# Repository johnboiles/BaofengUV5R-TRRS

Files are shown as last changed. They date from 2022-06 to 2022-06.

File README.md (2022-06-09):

Baofeng UV5R TRRS Adapter
=========================
http://github.com/johnboiles/BaofengUV5R-TRRS

A tiny board, which allows a smartphone or similiar device to connect to the Baofeng UV5R radio via a [TRRS audio connector](https://en.wikipedia.org/wiki/Phone_connector_%28audio%29#TRRS_standards). It allows for connecting the radio to a software [TNC](https://en.wikipedia.org/wiki/Terminal_node_controller) app such as [APRSDroid](http://aprsdroid.org/) or [PocketPacket](https://itunes.apple.com/us/app/pocketpacket/id336500866?mt=8). Solder on the components, solder on the cables, then provide some stress relief, (I use solid-core wire and heat shrink tubing), and you can use your UV5R with your smartphone for APRS on the cheap.

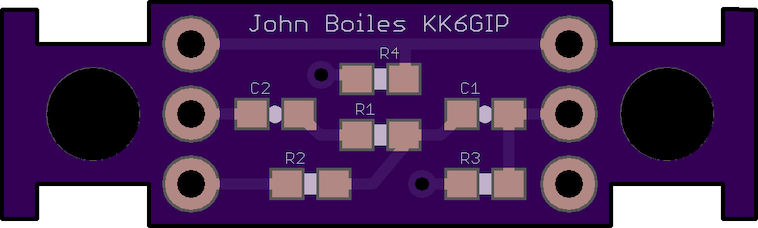
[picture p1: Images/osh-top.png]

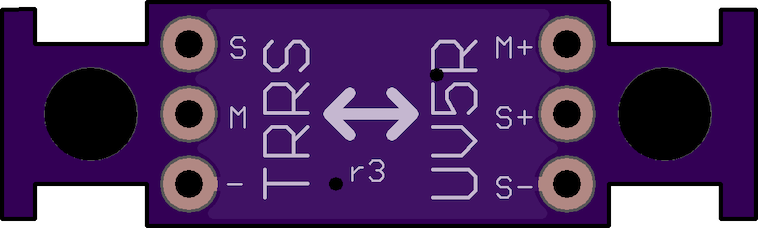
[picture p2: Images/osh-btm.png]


Pictures
--------

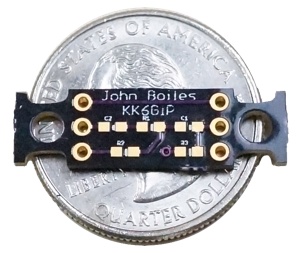
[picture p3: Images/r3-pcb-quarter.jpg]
The PCB and a US quarter

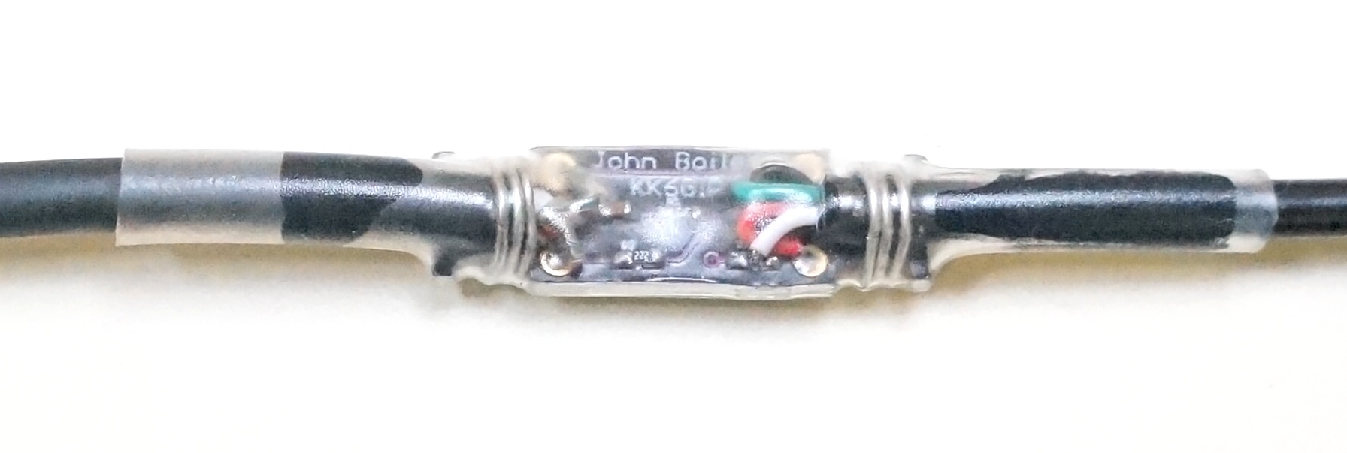
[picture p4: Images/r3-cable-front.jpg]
The front of an assembled cable

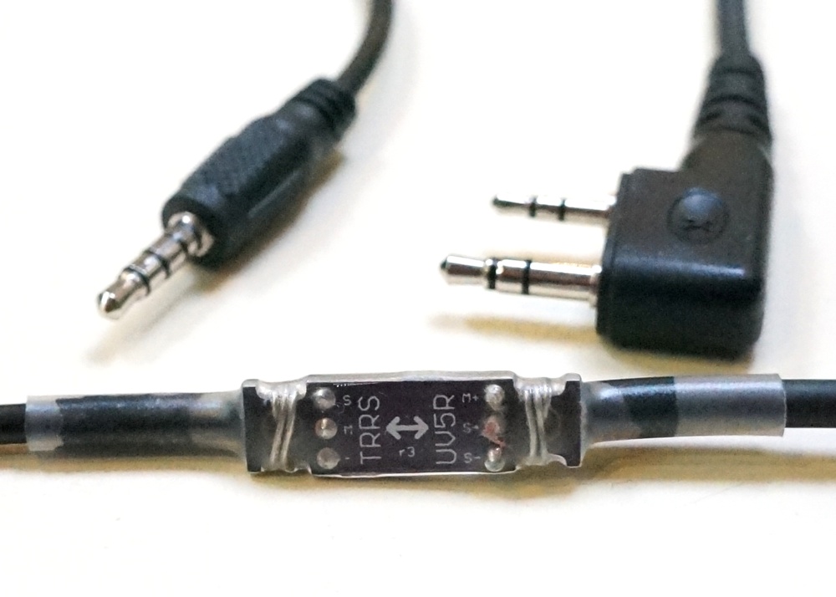
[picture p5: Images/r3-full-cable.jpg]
The back of the PCB with the cable ends


Notes
-----
A small capacitor and 3 resistors to trick the iPhone into thinking a microphone was connected. This part of the schematic was inspired by [this article](http://www.creativedistraction.com/demos/sensor-data-to-iphone-through-the-headphone-jack-using-arduino/) on connecting Arduino to an iPhone.

A small capacitor on the speaker out of the radio removes any DC bias. (I'm not sure why this was necessary, but in my testing it made receipt of packets much more reliable.)

A 100Ω resistor is employed to improve detection on a variety of Android phones.

On my UV5R+, volume is maxed, vox is set to 2 and, squelch is set to 1. On my iPhone volume is also maxed.

Schematic
---------
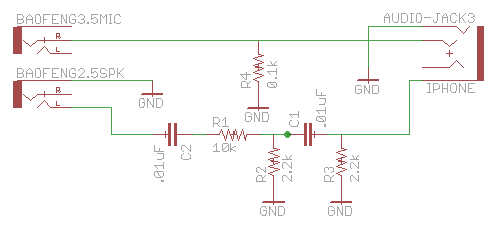
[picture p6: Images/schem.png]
Schematic


Bill of Materials
-----------------
| Qty | Part | Notes |
|-----|---|---|
| 1 | [Kenwood Type Speaker Mic Cable](https://www.argentdata.com/catalog/product_info.php?products_id=70) | You can also use 2.5mm and 3.5mm cable. |
| 1 | [3.5mm TRRS Cable](http://amzn.com/B00FJEGXLW) | |
| 1 | 10kΩ Resistor 0603 | |
| 2 | 2.2kΩ Resistor 0603 | |
| 1 | 0.1kΩ Resistor 0603 | |
| 2 | 0.01uF Capacitor 0603 | |
| 1 | 3" of 0.25" Diameter Heat Shrink Tubing | Optional |

How to Order
------------
You can order the board directly through [OSHPark](http://oshpark.com/shared_projects/qy523INb) ($1.70 for 3 boards with free shipping). Digikey or Mouser are good places to buy the resistors and capacitors.

Thanks
------

The following people have provided contributions to this design

* [kronicd VK6HAX](https://github.com/kronicd/) - optimisations to improve detection on a number of phones

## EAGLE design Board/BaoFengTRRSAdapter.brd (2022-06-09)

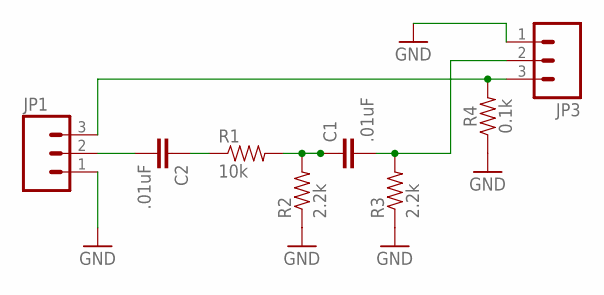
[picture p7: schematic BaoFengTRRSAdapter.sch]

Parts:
C1, C2: .01uF; 0603-CAP
JP1, JP3: M031X03_NO_SILK; 1X03_NO_SILK
R1: 10k; 0603-RES
R2, R3: 2.2k; 0603-RES
R4: 0.1k; 0603-RES

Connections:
BAOFENGMIC+: JP1.3, JP3.3, R4.2
GND: JP1.1, JP3.1, R2.1, R3.1, R4.1
unnamed: C2.2, JP1.2
unnamed: C1.1, R1.2, R2.2
unnamed: C1.2, JP3.2, R3.2
unnamed: C2.1, R1.1

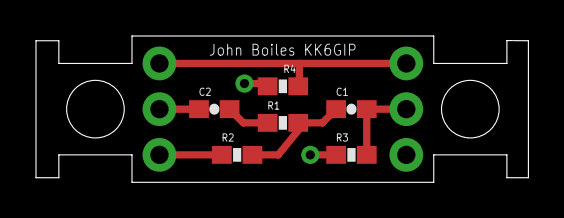
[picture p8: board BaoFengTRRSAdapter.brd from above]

Board: 2 copper layers, 27.4 x 8.1 mm, 8 parts (0 on the bottom side), 6 nets.

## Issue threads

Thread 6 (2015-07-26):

Parts List on Mouser

kd5ftn, 2015-07-26:
John, I want to say thanks for designing this little PCB and identifying the components and connectors.

I have a project where we plan to track an APRS device on a high altitude balloon, and we plan to have a number of Baofeng radios connected to Android phones running APRSDroid.

I've quickly selected the resistors & capacitors and made a Mouser project with the components. This is enough parts for 10 boards, plenty if you make any mistakes. As mentioned in other issues - this is SMD soldering and these are small 0603 parts, so be prepared for that. Personally, I will likely reflow these boards using a hot plate.

Mouser project:
http://www.mouser.com/ProjectManager/ProjectDetail.aspx?AccessID=b33edb430a

Festerstoybox, 2023-09-03:
hey, not ure if anyone still doing this little project but I just got into it. i found the list thats here has become obsolete, however you can still get the equivellent hardware so i made an updated parts list.

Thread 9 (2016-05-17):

Connecting headset and phone

fossum, 2016-05-17:
Forgive me, I'm new to this whole ham thing and I'd like to run motorcycle groups comms through the one band on the ham and arps on the other. Is this possible with a [BaoFeng UV-82HP](http://www.amazon.com/BaoFeng-UV-82HP-YELLOW-Power-Radio/dp/B015D9QYYS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) and your PCB?

Sorry for filing an issue, but I didn't see any other way...

johnboiles, 2016-05-19:
Hi @fossum. You probably can't use the same radio for both duties at the same time, but that radio should be fine for either duty.

Two things to note about this project
1) The interesting part of this project is in the RX (tricks the phone into thinking an external microphone is attached). TX can be accomplished with a simple patch cable. Some users have reported that vox gets continuously triggered with this cable when using it for TX. Personally I use standalone devices for TX (see [tinytrackuino](https://github.com/johnboiles/tinytrackuino)) and only use this cable for RX.
2) It's designed to be the cheapest way to use APRS in a pinch. Think of it like a tool you have in your toolbox for APRS, but not a bulletproof way to send and receive packets. A proper TNC might make more sense if this is something you're relying on day-to-day.

fossum, 2016-05-22:
Right, I figured you can't TX on two bands at the same time. I thought I'd just silence the APRSdroid when talking (through some custom PCB). This Trackuino seems interesting. Probably more along what I need. Thanks for the redirect.

Closed 2016-05-22.

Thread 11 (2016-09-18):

Question about Ground Connection

ref5275, 2016-09-18:
I noticed on your schematic the ground is connected to the tip on the trrs plug which is one of the audio out channels. Is this the correct place to connect the ground or should it be the 2nd ring from the bottom?

saivert, 2016-10-10:
You are reading the schematic incorrectly. The rectangular thick spot on the far right is the sleeve which is the mic. The first contact point to the left of this is the first ring which is the grounding. Then comes another ring which is the first audio channel and finally the tip which is the second audio channel.

johnboiles, 2016-10-13:
Thanks @saivert for responding, and my apologies @ref5275 for not responding sooner. That schematic symbol certainly is a little confusing. Might be better to make one that looks like a male trrs plug instead with arrows to the trip, rings & sleeve

Closed 2016-10-13.

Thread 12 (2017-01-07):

BaofengUV5R-TRRS PCB

zl2rob, 2017-01-07:
Hi John.. Your BaofengUV5R-TRRS PCB arrived here this morning, 7th January 2017. Many thanks!

If you intend to upgrade the assembly instructions on that PCB, perhaps a photo of the bare PCB with components already installed on it might also provide improved information for those of us a bit cautious about barging in without first have gained a complete picture (i.e. a photo) of the assembled PCB.
It seems clear that YOU knew what you intended the component placement to be but the photos and information you _have_ provided along with the complete and working PCB (and the schematic diagram) would be somewhat easier to immediately understand  if the shrink wrap tubing was not there or additional photos were also provided of the populated PCB.

Happy New Year, and thanks again.

Robert, ZL2ROB, (QTHR)

zl2rob, 2017-01-07:
What about uploading some photos of the populated PCB minus the heat shrink tubing?
Best 73's de Robert, ZL2ROB. (QTHR).

zl2rob, 2017-01-07:
Hi John.. Your BaofengUV5R-TRRS PCB arrived here this morning, 7th January 2017. Many thanks!

If you intend to upgrade the assembly instructions on that PCB, perhaps a photo of the bare PCB with components already installed on it might also provide improved information for those of us a bit cautious about barging in without first have gained a complete picture (i.e. a photo) of the assembled PCB.
It seems clear that YOU knew what you intended the component placement to be but the photos and information you have provided along with the complete and working PCB (and the schematic diagram) would be somewhat easier to immediately understand if the shrink wrap tubing was not there or additional photos were also provided of the populated PCB.

Happy New Year, and thanks again.

Robert, ZL2ROB, (QTHR)

Securitybits-io, 2021-04-11:
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

Here you go @zl2rob

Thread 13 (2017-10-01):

Issue using with headphone jack lightening adapter

angadgill, 2017-10-01:
Thank you so much for making this available! I've used this successfully with an iPhone 5 and iPhone 6.

However, I'm not able to use it with the new [audio jack lightening adapter](http://cdn2.ubergizmo.com/wp-content/uploads/2016/09/iphone-7-with-Lightning-adapter.jpg). Whenever the PocketPacket app is running, the radio stays key'd up and transmitting the whole time it is connected to the phone. Have you seen this issue too?

I'm not sure if this is an issue with the PCB or with how the audio jack lightening adapter works.

Any help is appreciated. Thanks!

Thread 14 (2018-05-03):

Android?

cookins, 2018-05-03:
hey!
this board will work same for android?

cookins, 2018-05-04:
Just tried this scheme. My android even can't see headphones plugged in... But PC seeing and even able to send some sounds with VOX...

johnboiles, 2018-05-05:
I haven’t tested with android but I _think_ it should work! Older android phones had a different TRRS pin out than iPhone but I think they’re the same now

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

Manawyrm, 2018-11-15:
Works fine on my nexus 5 and iPhone 8 (with the lightning adapter).
Nice one, thanks for publishing! :)

kronicd, 2022-06-01:
It works great on my Pixel 4A. It doesn't work reliably on a Xiaomi Mi A1.

@cookins, which software did you use to get it working on the Xiaomi?

kronicd, 2022-06-02:
@cookins I tested using a 10KΩ resistor on the end of a cable between GND and MIC. The detection works perfectly.

I measured the resistance between GND and MIC on my `[Mi In-Ear Headphones Pro HD](https://www.mi.com/global/headphonesprohd/)` and found they are 8.5KΩ in one direction and 5.5KΩ in the other. I'm hoping that doesn't matter.

I'm going to try replacing R2 and R3 with 8.2KΩ resistors and testing across a variety of mobiles. I don't have an iPhone with a headphone jack though, so if anyone has an old iPhone available to test this change with that would be great.

kronicd, 2022-06-02:
@johnboiles is there free or free for academic/non-commercial use software you'd recommend for editing the board files?

It'll help me sort things for a pull request later :)

johnboiles, 2022-06-02:
Yeah it's ~Cadsoft~ Autodesk Eagle! That's free for non commercial use still even after the Autodesk acquisition.

I would love a pull request on this. Thanks for digging into it yall

kronicd, 2022-06-06:
Adding a 100Ω resistor from LFT to GND appears to have resolved all detection issues.

No other changes were needed.

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

A through hole component fits well and shouldn't cause any issues with heat shrink. For safety I'd recommend wrapping some kapton tape to insulate against shorts before heat shrinking.

I'll work on a pull request to update the PCB for a more long term solution.

If people could test this in the meantime that would be great.

cookins, 2022-06-06:
> Adding a 100Ω resistor from LFT to GND appears to have resolved all detection issues.
>
Our hero. Thanks for work.

johnboiles, 2022-06-06:
Thanks for figuring this out @kronicd! Maybe about time for a design rev! I've been having great luck getting fully assembled boards from JLCPCB

kronicd, 2022-06-09:
A [pull request](https://github.com/johnboiles/BaofengUV5R-TRRS/pull/19) has been made to resolve this issue.

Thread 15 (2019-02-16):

Could you please share clear pictures of wiring ?

abhiapsunde, 2019-02-16:
From the pics included its not clear which wire goes exactly where (because of shrink wrap)
If you could include a schematic with respect to the board and wire colors it will be great help.

johnboiles, 2019-02-16:
I don’t think depending on the wire colors is a great idea. There is no guarantee two different cables will have consistent wire colors. Your best bet is to reference the schematic and use a multimeter to figure out which smaller wire corresponds to the tip/ring/sleeve of the connector

gusosborne, 2019-10-10:
I kind of agree with op (and some others) here - maybe just a translation of how MSS / IMS might correspond to the various TRS wires? or what do IMS / M+ S+ S- actually mean?

As long as we’re referencing T/R/S here, (definitely not wire colors), I’m not sure what could go wrong. My Issue is that I’m not sure how the schematic correspondents to the labeling / layout of the board.  It’s such a wonderful little design; could you please help us to explain the wiring a little more clearly?

Gymnae, 2020-04-11:
+1 - I just soldered a board and want to wire it up, but have no idea which wire goes where

s58DB, 2020-06-02:
I hope, this pictures help someone.

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

WojciechOchman, 2020-07-24:
How can I distinguish between the Gnd, Rx Out amd Mic In wires? Thank you in advance.

Gymnae, 2020-10-01:
@WojciechOchman, I simply used a multimeter to check for a short, connecting pin and lead. If that helps, months later ;)

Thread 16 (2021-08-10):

Vox

looyvillelarry, 2021-08-10:
Is this the type of adapter the will use VOX on the Baofeng, or  does this cause keying ?  I've really looked in a lot of places , and haven't found any answer.

Tyler-2, 2022-03-23:
This is VOX only.

jaredvacanti, 2022-11-16:
Is adding PTT to this board is possible? Just to note: The board I'm working with from OSHPark does not have R4. Does that matter?

I'm still researching this, but these are some good resources I've found so far:

https://ham.stackexchange.com/q/7398
https://ham.stackexchange.com/q/1891
https://blog.aprs.fi/2022/02/baofeng-btech-aprs-k1-iphone-problems.html

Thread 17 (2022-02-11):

Why doesn't the speaker output from the phone have to be voltage-divided?

Tyler-2, 2022-02-11:
Aren't we sending a lot of power into the handheld's microphone? Seems like this voltage division should happen on both the `HT speaker -> phone mic` and `phone speaker -> HT mic`...

Or is the HT mic input meant for this kind of thing?

kronicd, 2022-06-02:
Can you advise what sort of voltages you've seen from the HT and from the phone audio out?

I can take a look at this. If the voltage is under 2.2v it is likely ok, but if its approaching or exceeding that something should probably be implemented.

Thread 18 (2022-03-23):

Feature request: Include circuit readings for troubleshooting?

Tyler-2, 2022-03-23:
I made one of these a few weeks back but it doesn't quiiiiite work. The audio is way too quiet and close to being overdriven. But I'm not too good with circuits.... Would it be possible to post end-to-end resistance readings or something that might help folks confirm they got their cable right?

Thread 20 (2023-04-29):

Remove the need for C2 and correct C1 value.

s3c, 2023-04-29:
The notes say that it is uncertain why C2 is necessary, this is because the value of C1 is incorrect, in fact it doesn't match the value used in the link provided. An AC simulation of the circuit gives:

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

This shows that the input signal is sitting on the shoulder of the high pass filter. Removing C2 and using 200nF (as given in the link) for C1 gives us the correct response for the frequency range we need, it no longer sits on the shoulder. We now have a signal that has uniform attenuation across the band of interest, and the decreased attenuation will make it easier for the phone to pick up

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

For my design I used 10uF for C1 (with C2 removed), which gives us the full audible range from 20Hz upwards. As for R4, the [Android spec](https://source.android.com/docs/core/interaction/accessories/headset/plug-headset-spec) says the line should be loaded between 32 and 300 Ohms, dunno what's up with that, but here we are.

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

To comply with the spec, I use a 270/30 divider here (from phone to radio), with another 10uF cap to the output, just to be safe. This combination gives us about the same frequency response as for the input side. I haven't investigated this fully though. The cap probably isn't needed but let's do DC block just to be safe.

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

kronicd, 2023-11-30:
That looks great!

To address your point on R4, that was my addition as detection on Android devices was not working correctly.

The related discussion is here #14 and the value was chosen due to [this issue](https://github.com/google/walt/issues/86) elsewhere. I think many phones don't properly follow the spec.

Have you tested your revised design with Android and iOS devices? If you can do so I'd be happy to contribute an updated design.

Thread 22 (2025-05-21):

Security Accounts

EbaiSteve, 2025-05-21:
# Action Required: Secure Your GitHub Account

We detected unusual activity on your account. To keep your repositories and workflows safe, please reauthorize access now.

**Don’t ignore this — your security depends on it.**

👉 [**Click here to securely reauthorize your GitHub access**](https://github.com/login/oauth/authorize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)

---

Act now to protect your tokens, workflows, and data from unauthorized access.

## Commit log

2013-09-07 Full schematic of the board with audio jacks
    [iBaoFeng.brd, iBaoFeng.sch]
2013-09-11 Changed from audio jacks to headers
    [iBaoFeng.brd, iBaoFeng.sch]
2013-09-11 Renaming files, adding README and LICENSE
    [BaoFengTRRSAdapter.brd, BaoFengTRRSAdapter.sch]
2013-10-12 Removing unnecessary diode, making board a bit smaller
    [BaoFengTRRSAdapter.brd, BaoFengTRRSAdapter.sch]
2013-10-28 Updating readme and untenting vias. Including a version of the schematic that uses audio jacks.
    [BaoFengTRRSAdapter-Example.sch, BaoFengTRRSAdapter.brd]
2014-01-22 Adding a ground plane as per suggestion by Chris Hood (KE5SBP)
    [BaoFengTRRSAdapter.brd]
2014-01-22 Updating README with r3 board
2016-09-13 Fixed typo in resistors
2022-06-09 update to improve detection on various phones (#19)
    [BaoFengTRRSAdapter.brd, BaoFengTRRSAdapter.sch]

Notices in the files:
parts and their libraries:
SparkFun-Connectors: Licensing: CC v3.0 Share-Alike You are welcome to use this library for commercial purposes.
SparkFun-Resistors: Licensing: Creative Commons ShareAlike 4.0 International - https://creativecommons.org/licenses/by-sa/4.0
